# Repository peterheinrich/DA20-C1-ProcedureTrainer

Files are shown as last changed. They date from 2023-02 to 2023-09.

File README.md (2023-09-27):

# DA20-C1-ProcedureTrainer
DA20 Hardware Cockpit Simulator for Procedure Training (non approved simulator)

# Final Training Setup
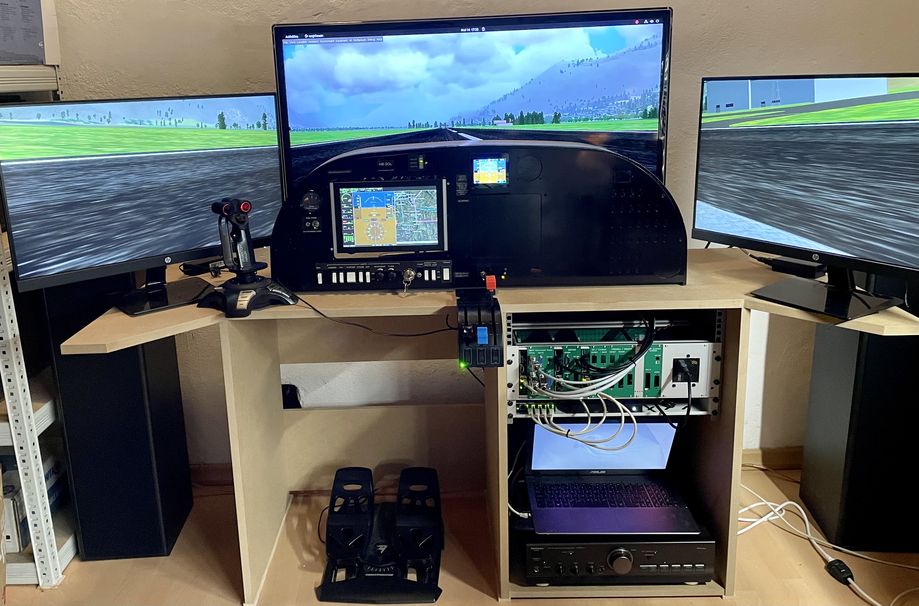
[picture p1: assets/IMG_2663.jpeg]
Final Training Setup


# Generic Instrument I/O Card based on Raspberry-PI CM4
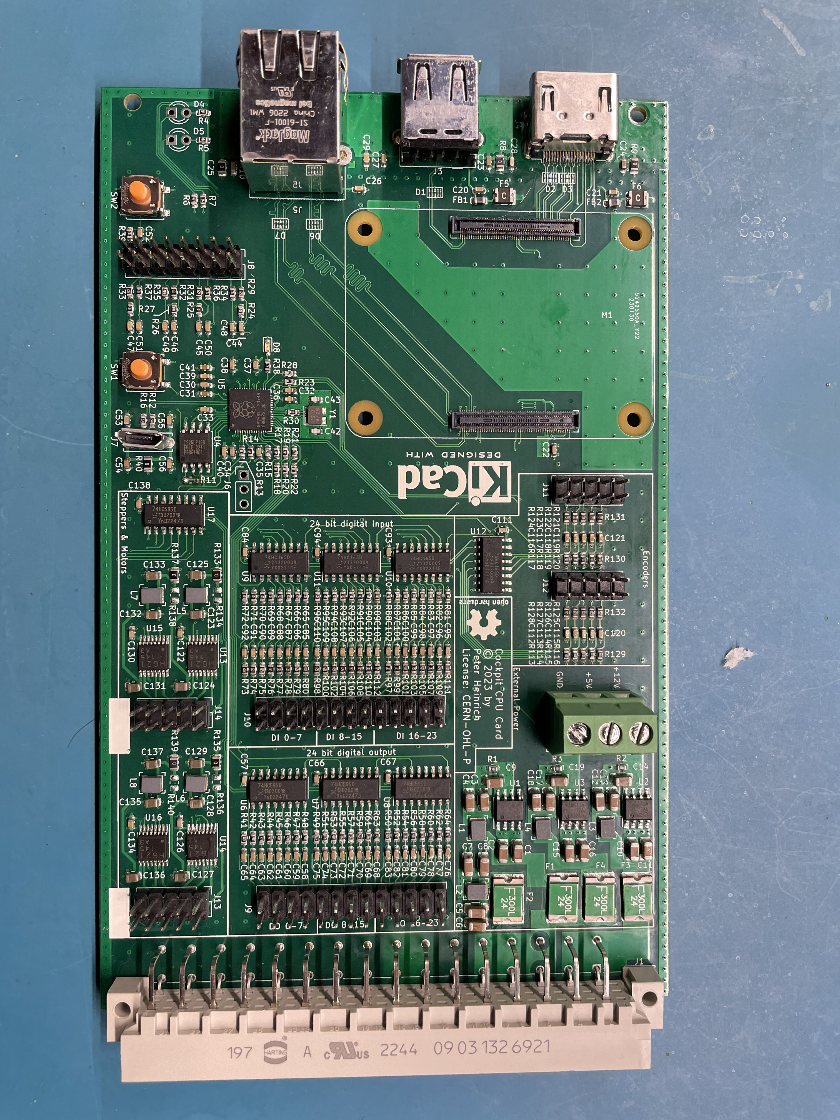
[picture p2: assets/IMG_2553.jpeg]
Cockpit CPU Card

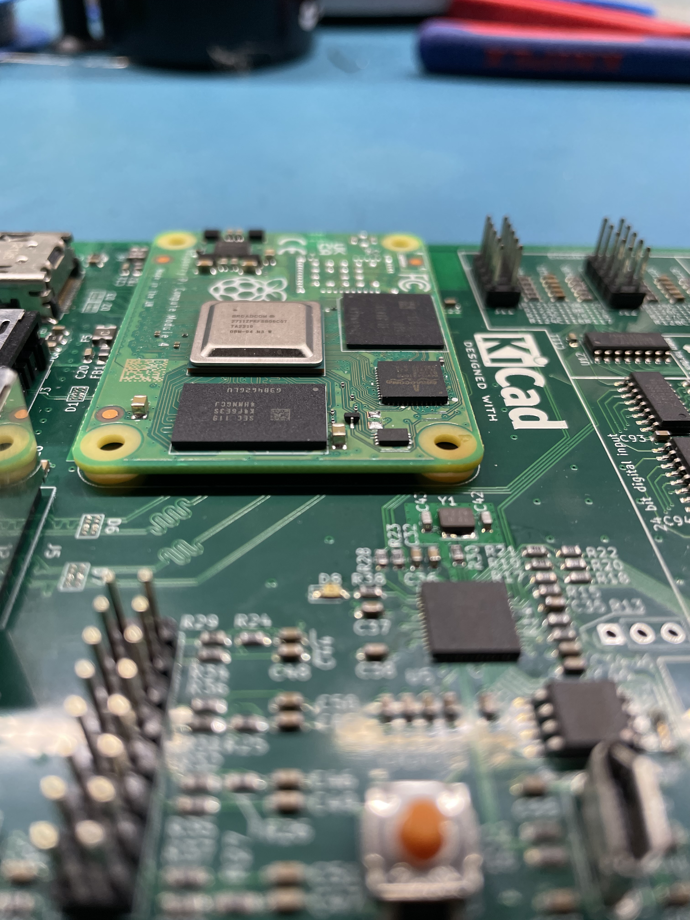
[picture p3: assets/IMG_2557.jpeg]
With Raspberry-PI CM4 installed


# Running with FgFs (FlightGear Flight Simulator)

/usr/local/fgfs.app/Contents/MacOS/fgfs --fg-scenery=/Users/peter/Development/flightgear/terraGIT --airport=LSMF --enable-auto-coordination --aircraft=DA20-C1 --httpd=8080 --generic=socket,out,10,255.255.255.255,30000,udp,glasspanel-stream --timeofday=noon --altitude=10000

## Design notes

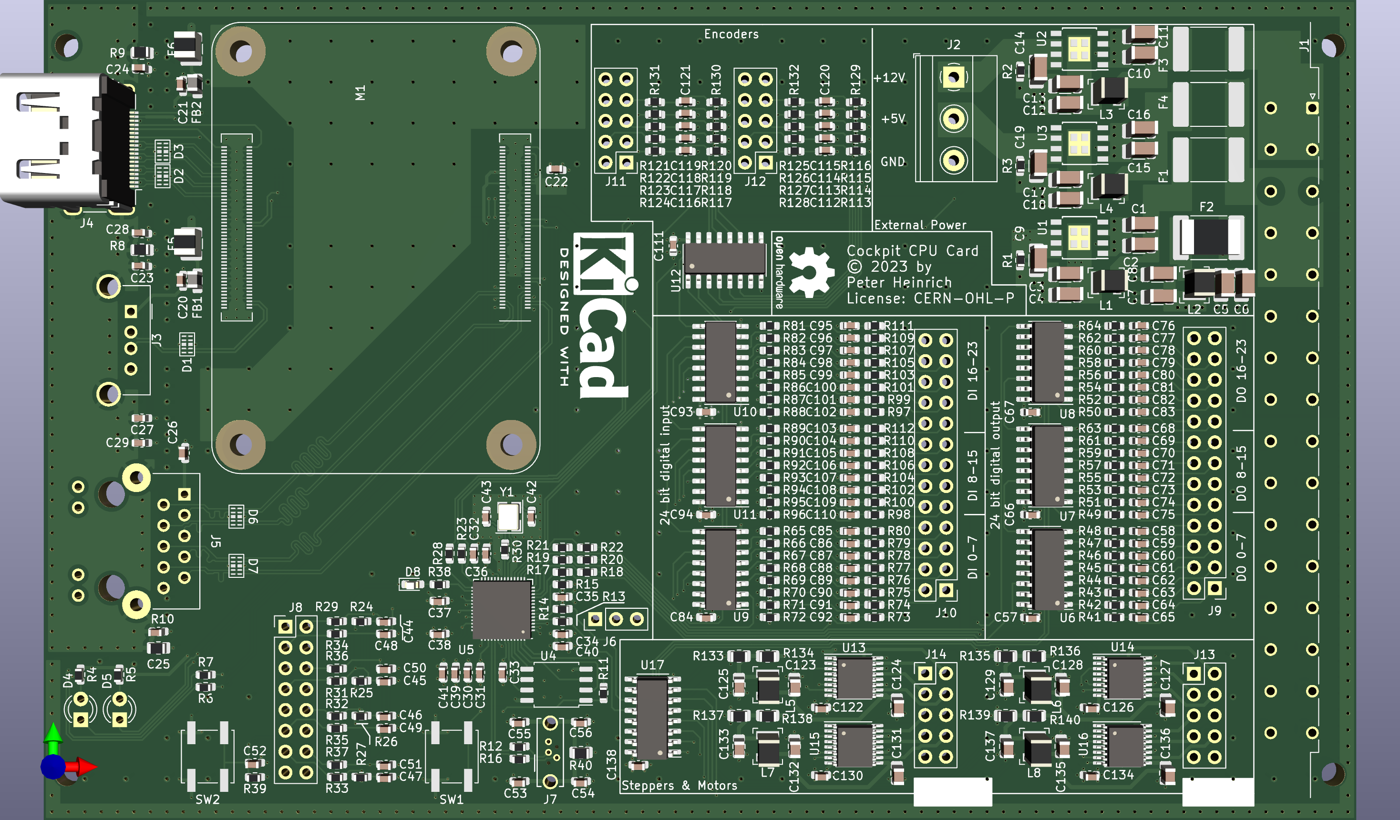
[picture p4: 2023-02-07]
assets/Cockpit-CPU-Card.png

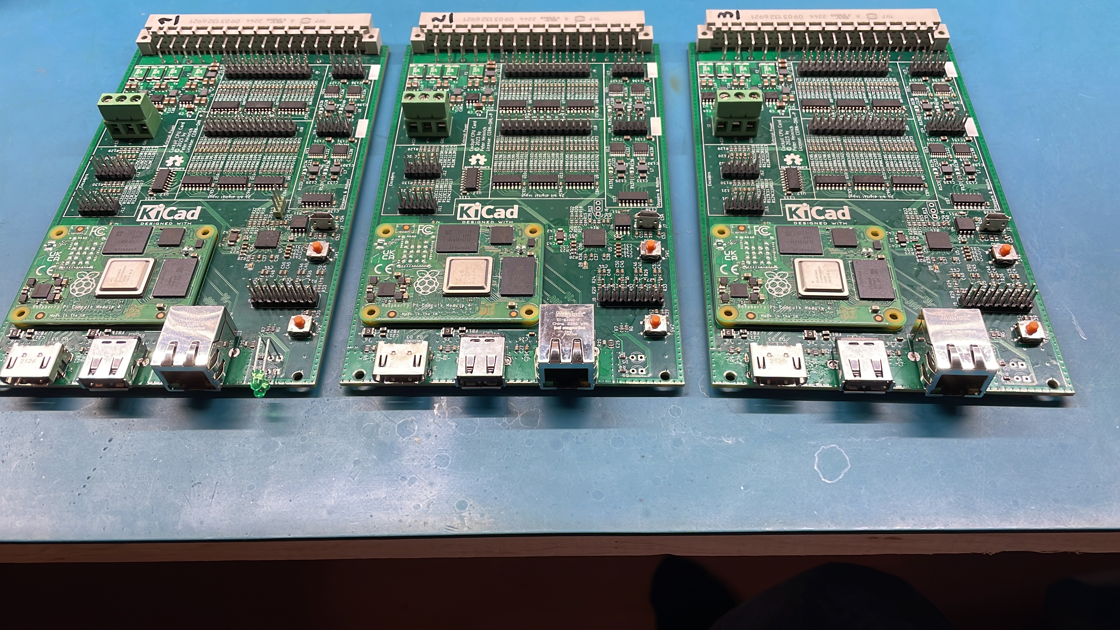
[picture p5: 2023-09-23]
assets/D262D218-E119-4301-A444-4E6CBF223C45.jpg

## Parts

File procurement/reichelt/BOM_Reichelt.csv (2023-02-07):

Quantity | Order Number | Description/MPN
1 | BQT BN323 | Netzteil be quiet! TFX Power 3 300W Gold
1 | BGT TFP 342 | Alu-Teilfrontplatten 128,4 x 213,2 x 2,5mm
6 | HS 25-14 | Hohlstecker Knickschutz, Ø außen: 5,5 mm, Ø innen: 2,5 mm
2 | HEBL 21 | Einbaubuchse Zentraleinbau, Ø außen: 5,6 mm, Ø innen: 2,1 mm
1 | BGT 384-240 | 19 Zoll-Baugruppenträger, 3HE 84TE, 238 mm tief
5 | LIYCY 10-5 | Steuerleitung 10x0,14mm², geschirmt, 5m-Ring
18 | KAPPE 25M | D-SUB-Kappe f. 25-polig D-Sub, metallisiert
8 | KAPPE 15M | D-SUB-Kappe f. 15-polig D-Sub, metallisiert
26 | KAPPE 09M | D-SUB-Kappe f. 9-polig D-Sub, metallisiert
12 | D-SUB ST 25 | D-SUB-Stecker, 25-polig, Lötkelch
15 | D-SUB BU 25 | D-SUB-Buchse, 25-polig, Lötkelch
18 | D-SUB ST 09 | D-SUB-Stecker, 9-polig, Lötkelch
2 | MOLEX 39301240 | Molex, Stiftleiste - Mini-Fit Jr - 2x12-polig - Stecker
5 | HAN 03 132 6921 | Messerleiste C, gewinkelt, 32-pol
15 | PFL 10 | Pfostenbuchse, 10-polig, mit Zugentlastung
1 | AWG 28-26G 3M | Flachbandkabel AWG28, 26-pol., grau, 3m-Ring
6 | D-SUB ST 25FB | D-SUB-Stecker, 25-pol, Flachbandkabel, ohne Isolator
5 | D-SUB ST 09FB | D-SUB-Stecker, 9-pol, Flachbandkabel, ohne Isolator
10 | BGT FSC 160 | Kartenführung zum Einrasten, 160 mm (Fischer)
5 | BGT SFP 304 | Alu-Steckfrontplatten 128,4 x 20,0 x 2,5mm
5 | D-SUB BU 09FB | D-SUB-Buchse, 9-pol, Flachbandkabel, ohne Isolator
4 | D-SUB BU 15FB | D-SUB-Buchse, 15-pol, Flachbandkabel, ohne Isolator
3 | D-SUB BU 25FB | D-SUB-Buchse, 25-pol, Flachbandkabel, ohne Isolator
5 | PFL 16 | Pfostenbuchse, 16-polig, mit Zugentlastung
10 | PFL 26 | Pfostenbuchse, 26-polig, mit Zugentlastung
52 | SV U | D-SUB-Befestigungssatz, 2 Bolzen mit Muttern
1 | NKSK CH 180 | Netzkabel, CH Stecker, Typ J, 1,8 m, schw, C13
5 | HAN 03 232 6824 | Federleiste C, gerade, 32-pol
21 | D-SUB BU 09 | D-SUB-Buchse, 9-polig, Lötkelch
8 | D-SUB ST 15 | D-SUB-Stecker, 15-polig, Lötkelch
2 | LIYCY 25-5 | Steuerleitung 25x0,14mm², geschirmt, 5m-Ring
1 | BGT 384-2 | Gewindestreifen
4 | LIYCY 04-5 | Steuerleitung 4x0,14mm², geschirmt, 5m-Ring
6 | HEBL 25 | Einbaubuchse Zentraleinbau, Ø außen: 5,6 mm, Ø innen: 2,5 mm
2 | HS 21-9 | Hohlstecker Knickschutz, Ø außen: 5,5 mm, Ø innen: 2,1 mm

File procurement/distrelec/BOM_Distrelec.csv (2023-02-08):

Quantity | Order Number | Description/MPN
204 | 300-56-474 | 1550603SAF1200T5E

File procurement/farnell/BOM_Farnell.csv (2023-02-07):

Quantity | Order Number | Description/MPN
114 | 3013515 | CL31A226KAHNNNE
618 | 3013413 | CL10B104KO8NNNC
12 | 3013384 | CL10A105KO8NNNC
12 | 2773145 | C0603C270K5GACTU
72 | 3013460 | CL21A226MPCLRNC
30 | 4035994 | HSP054-4N10
12 | 1581123 | MCL034GT
6 | 2322073 | 150060VS75000
24 | 3020672 | MC011393
12 | 1596997 | 1210L020WR
12 | 1515661 | BLM21PG221SN1D
6 | 1096917 | 09 04 132 6921
6 | 2008005 | MC000035
6 | 1450206 | 67643-0910.
6 | 3465045 | 208658-1001
6 | 1572191 | SI-61001-F
6 | 1248141 | 826926-3
6 | 2470821 | 614105150721
6 | 1593445 | 2213S-16G
6 | 3225996 | M20-9761346
6 | 3225996 | M20-9761346
6 | 2751378 | 67997-410HLF
6 | 2751378 | 67997-410HLF
12 | 2751378 | 67997-410HLF
48 | 3974271 | SRP3212-3R3M
12 | 2427679 | DF40C-100DS-0.4V(51)
504 | 2073356 | MCMR06X103 JTL
174 | 2073508 | MCMR06X4700FTL
6 | 2447359 | MCWR06X3301FTL
12 | 2447316 | MCWR06X27R0FTL
66 | 2447339 | MCWR06X3300FTL
6 | 2073348 | MCMR06X1001FTL
24 | 9333681 | MC01W08050R
12 | 2320051 | KSC441J70SHLFS
18 | 2480570 | BTS50301EJAXUMA1
6 | 2901144 | IS25LP128F-JBLE
6 | 3766082 | RP2040CT
24 | 1201269 | 74HC595D,118
24 | 1201249 | 74HC165D,653
24 | 3869999 | TC78H621FNG
6 | 2308709 | ABM8G-12.000MHZ-18-D2Y-T

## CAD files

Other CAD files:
mcad/G5_Case.scad

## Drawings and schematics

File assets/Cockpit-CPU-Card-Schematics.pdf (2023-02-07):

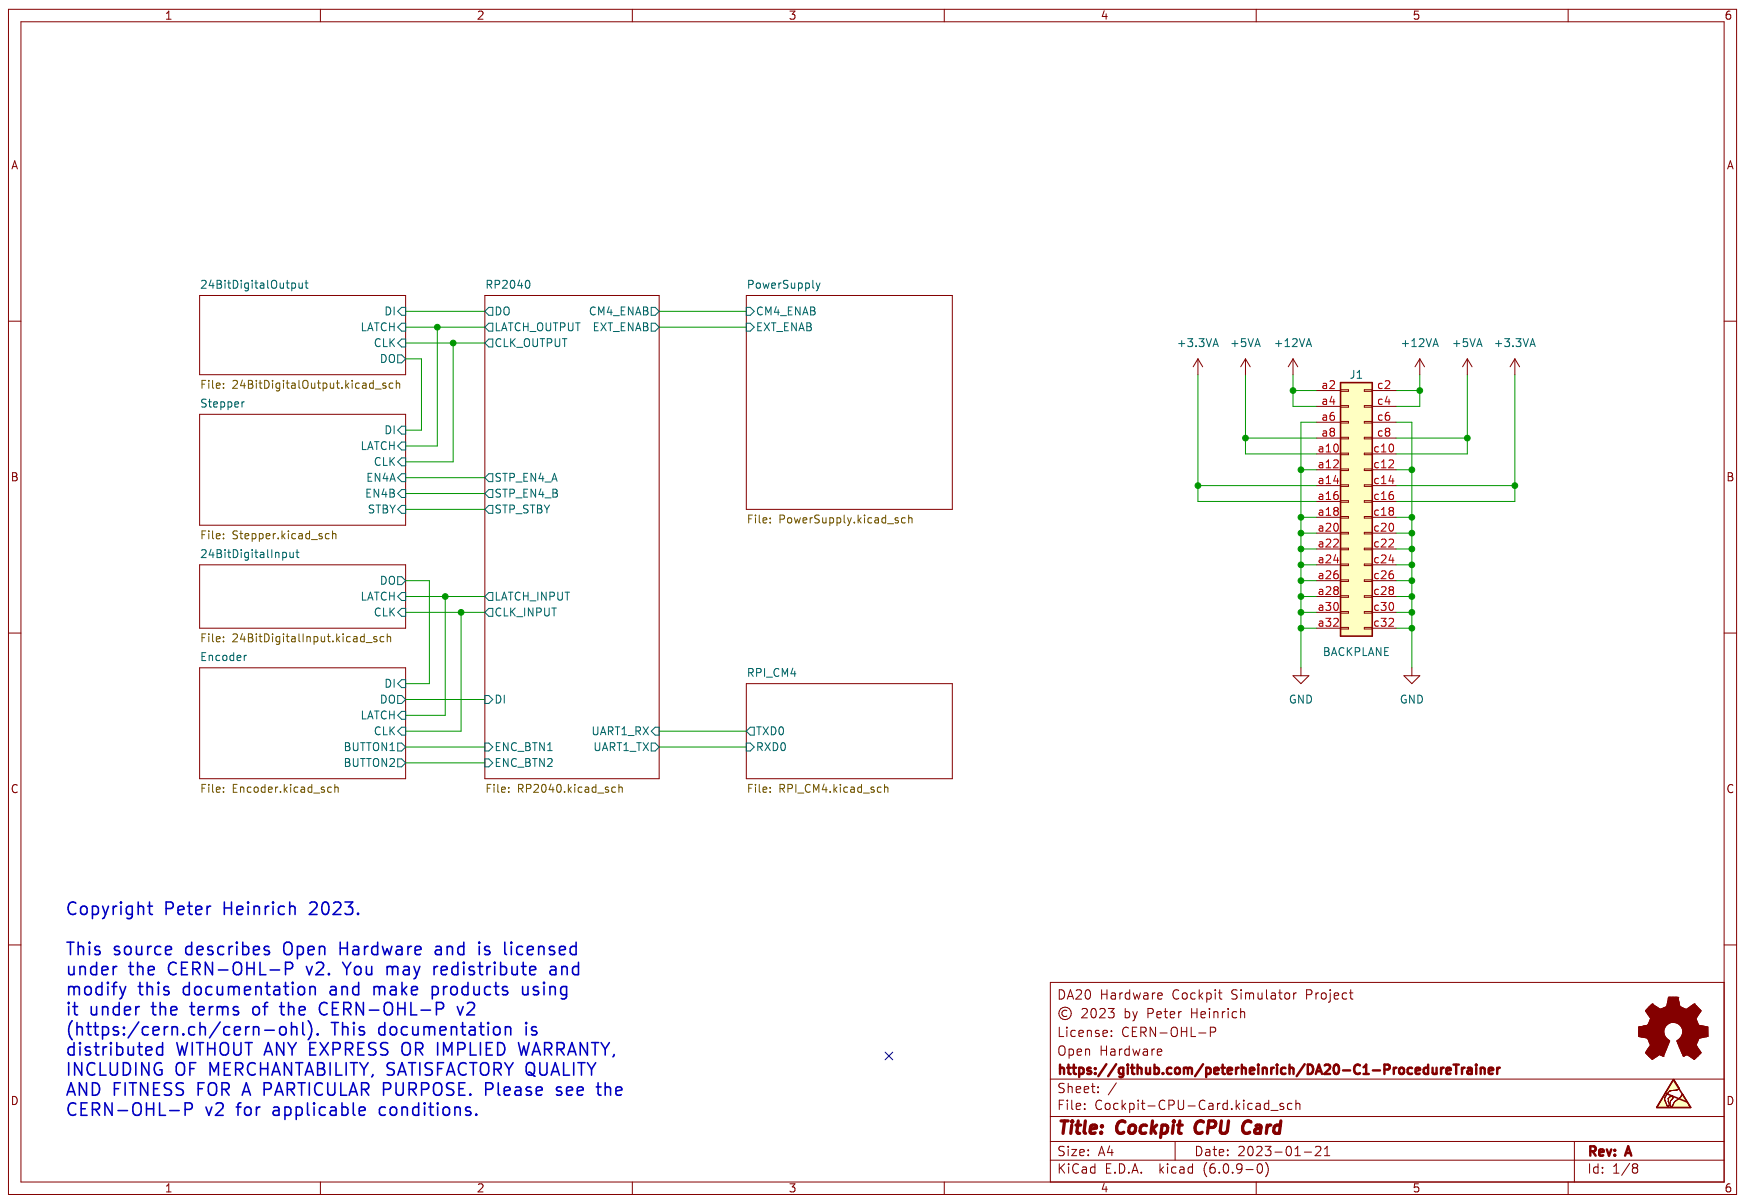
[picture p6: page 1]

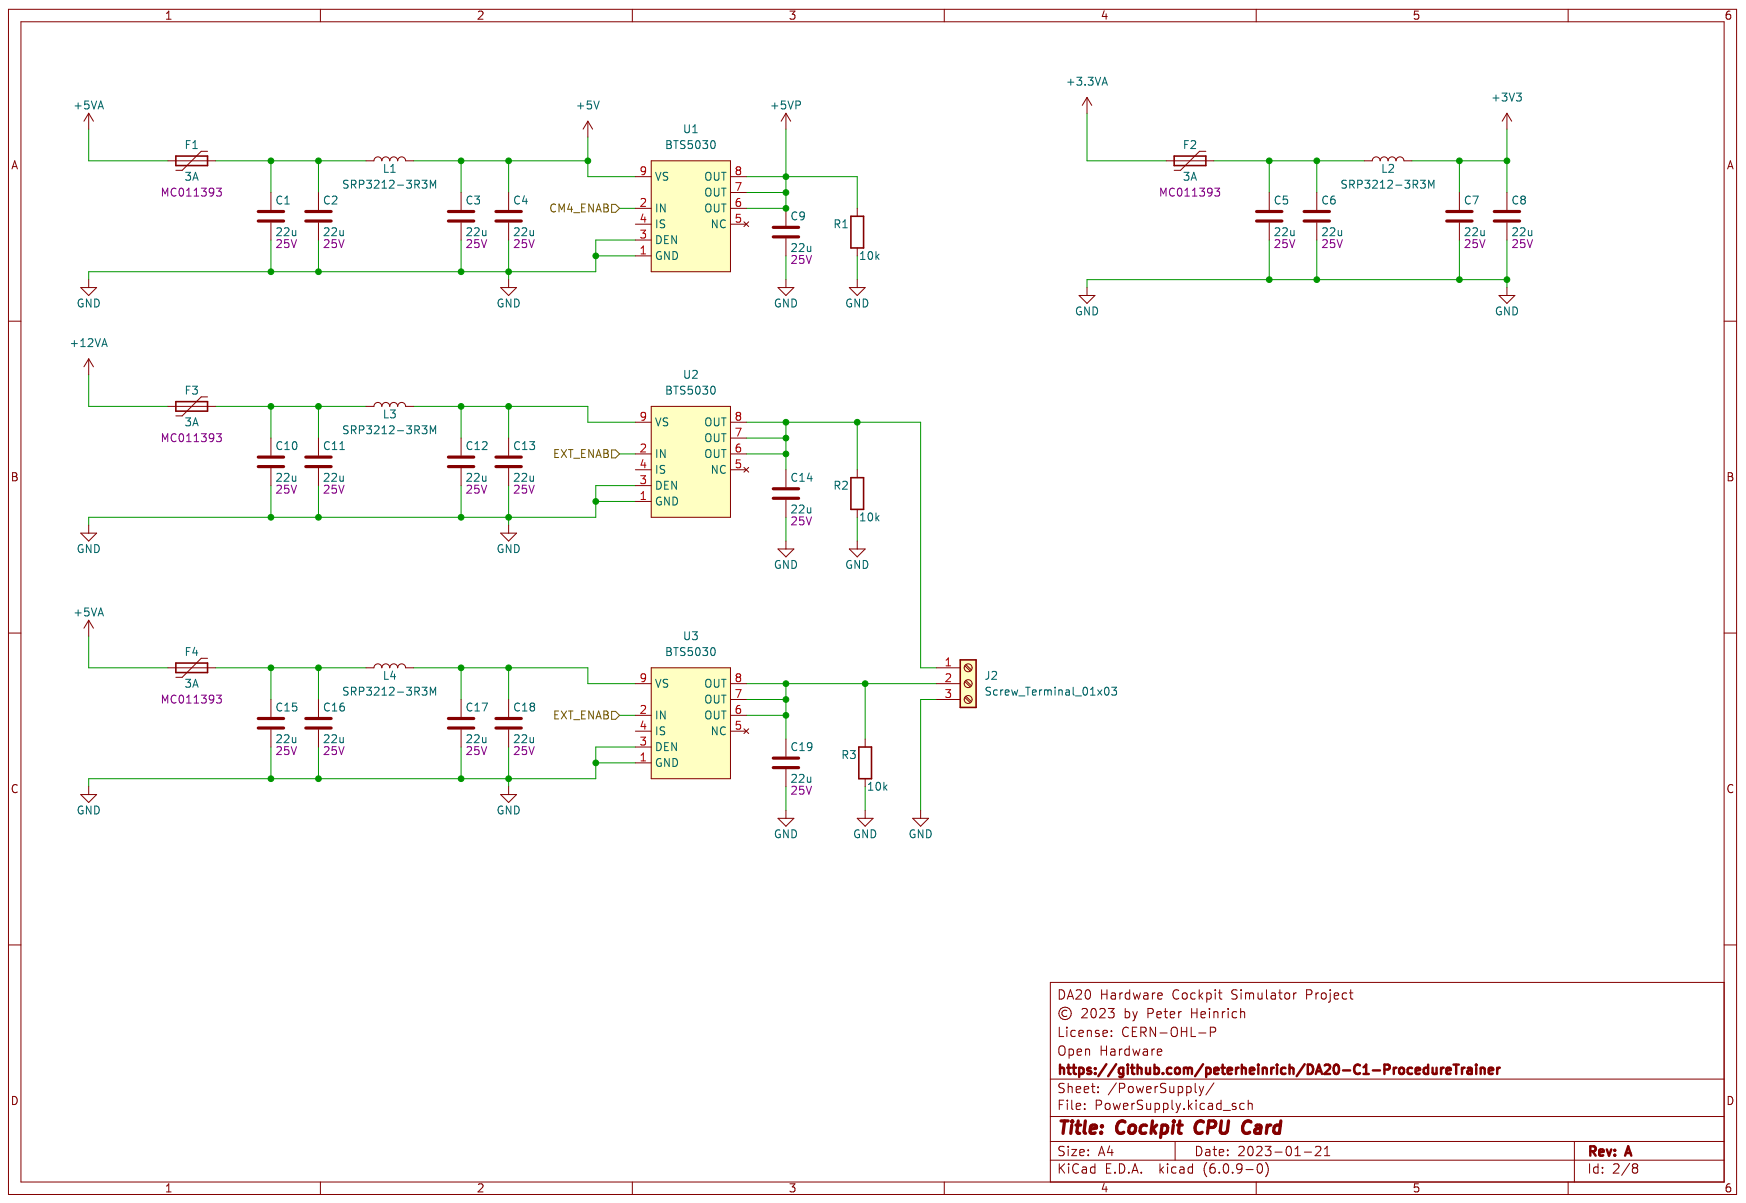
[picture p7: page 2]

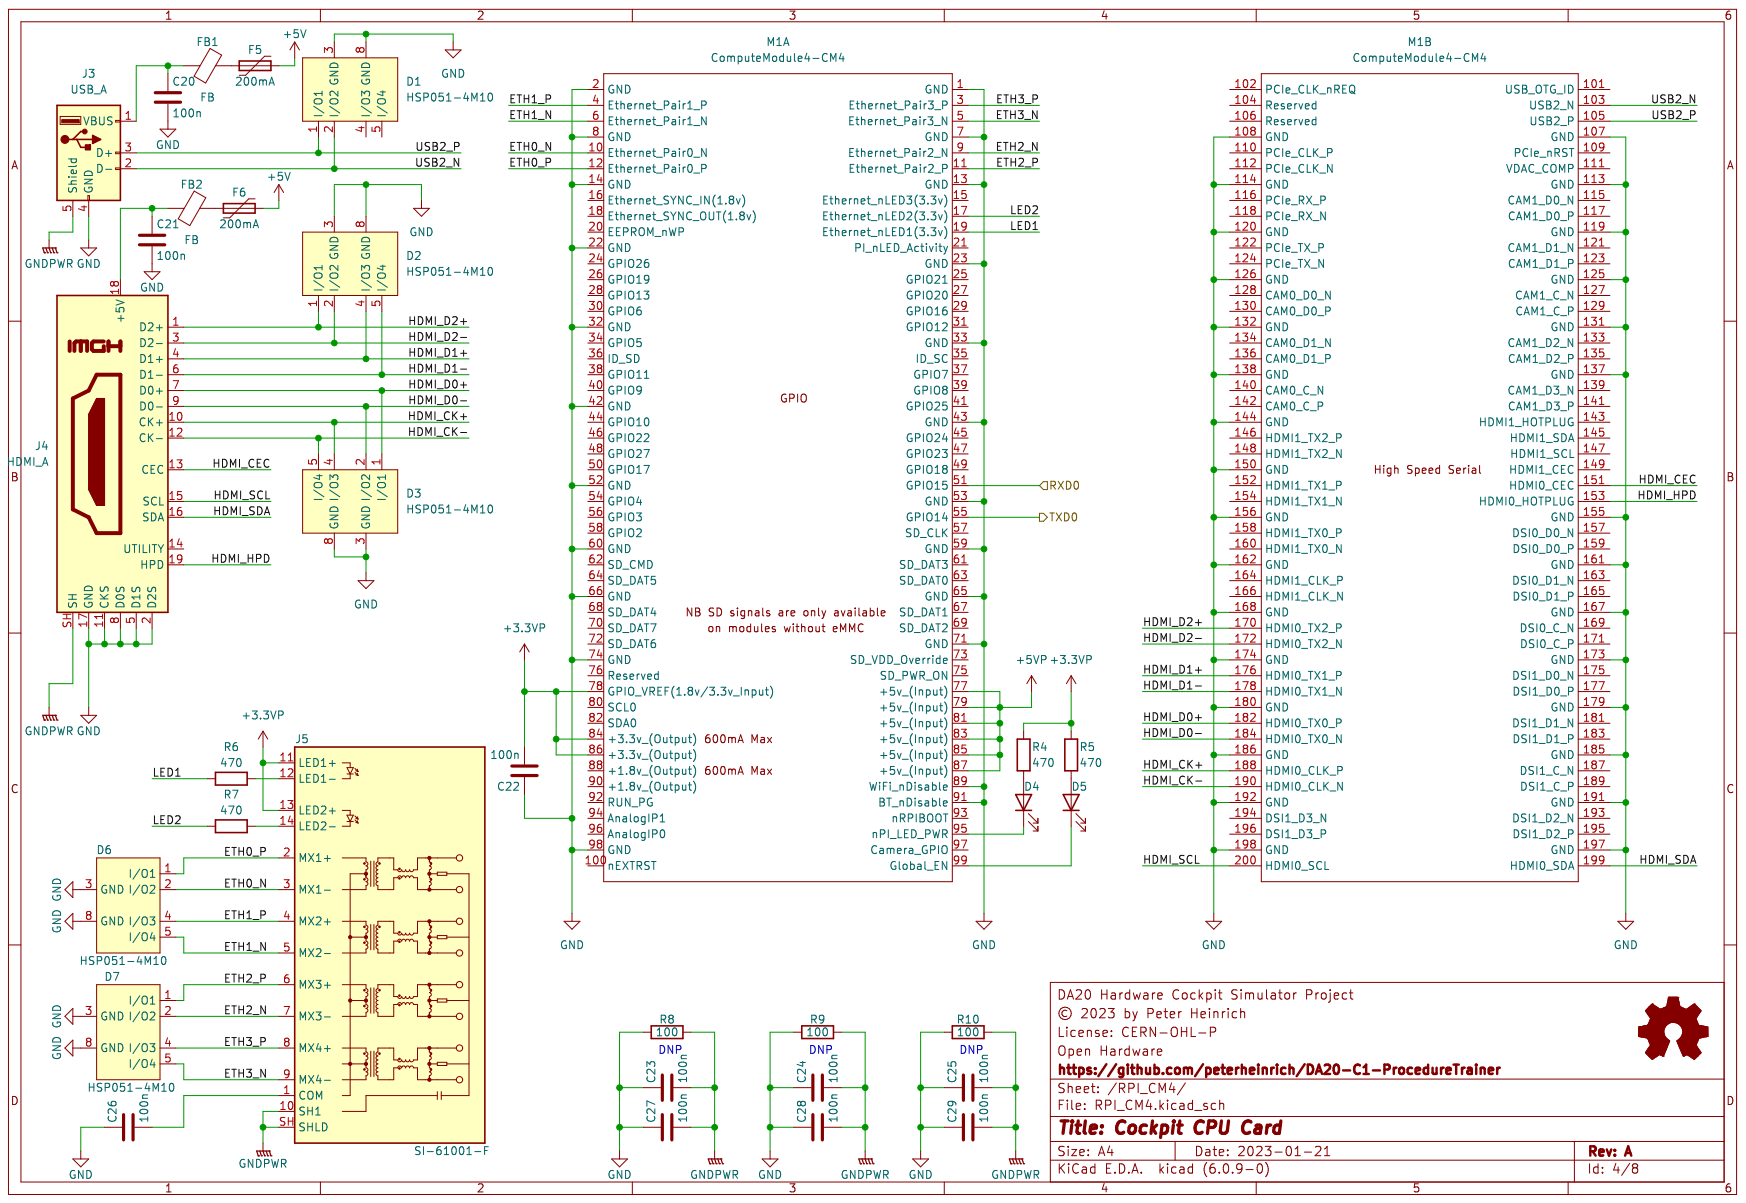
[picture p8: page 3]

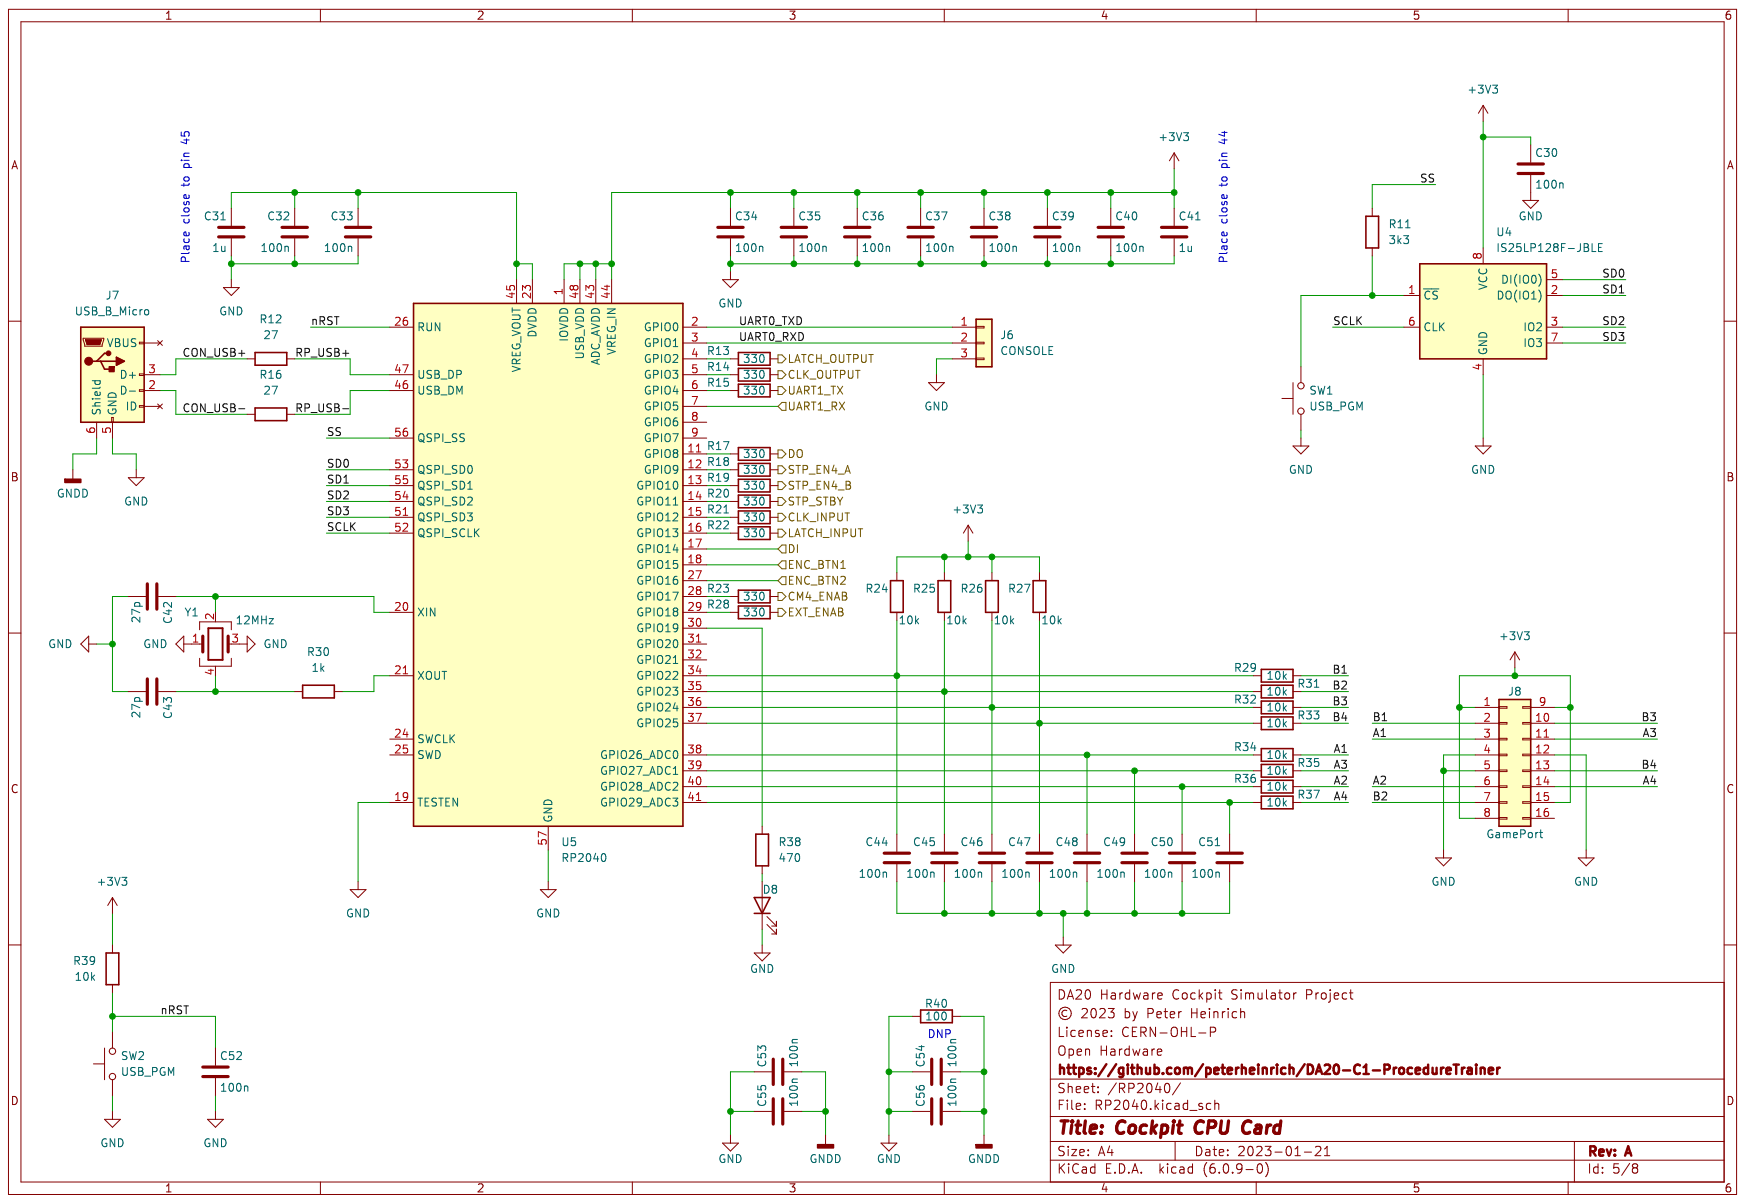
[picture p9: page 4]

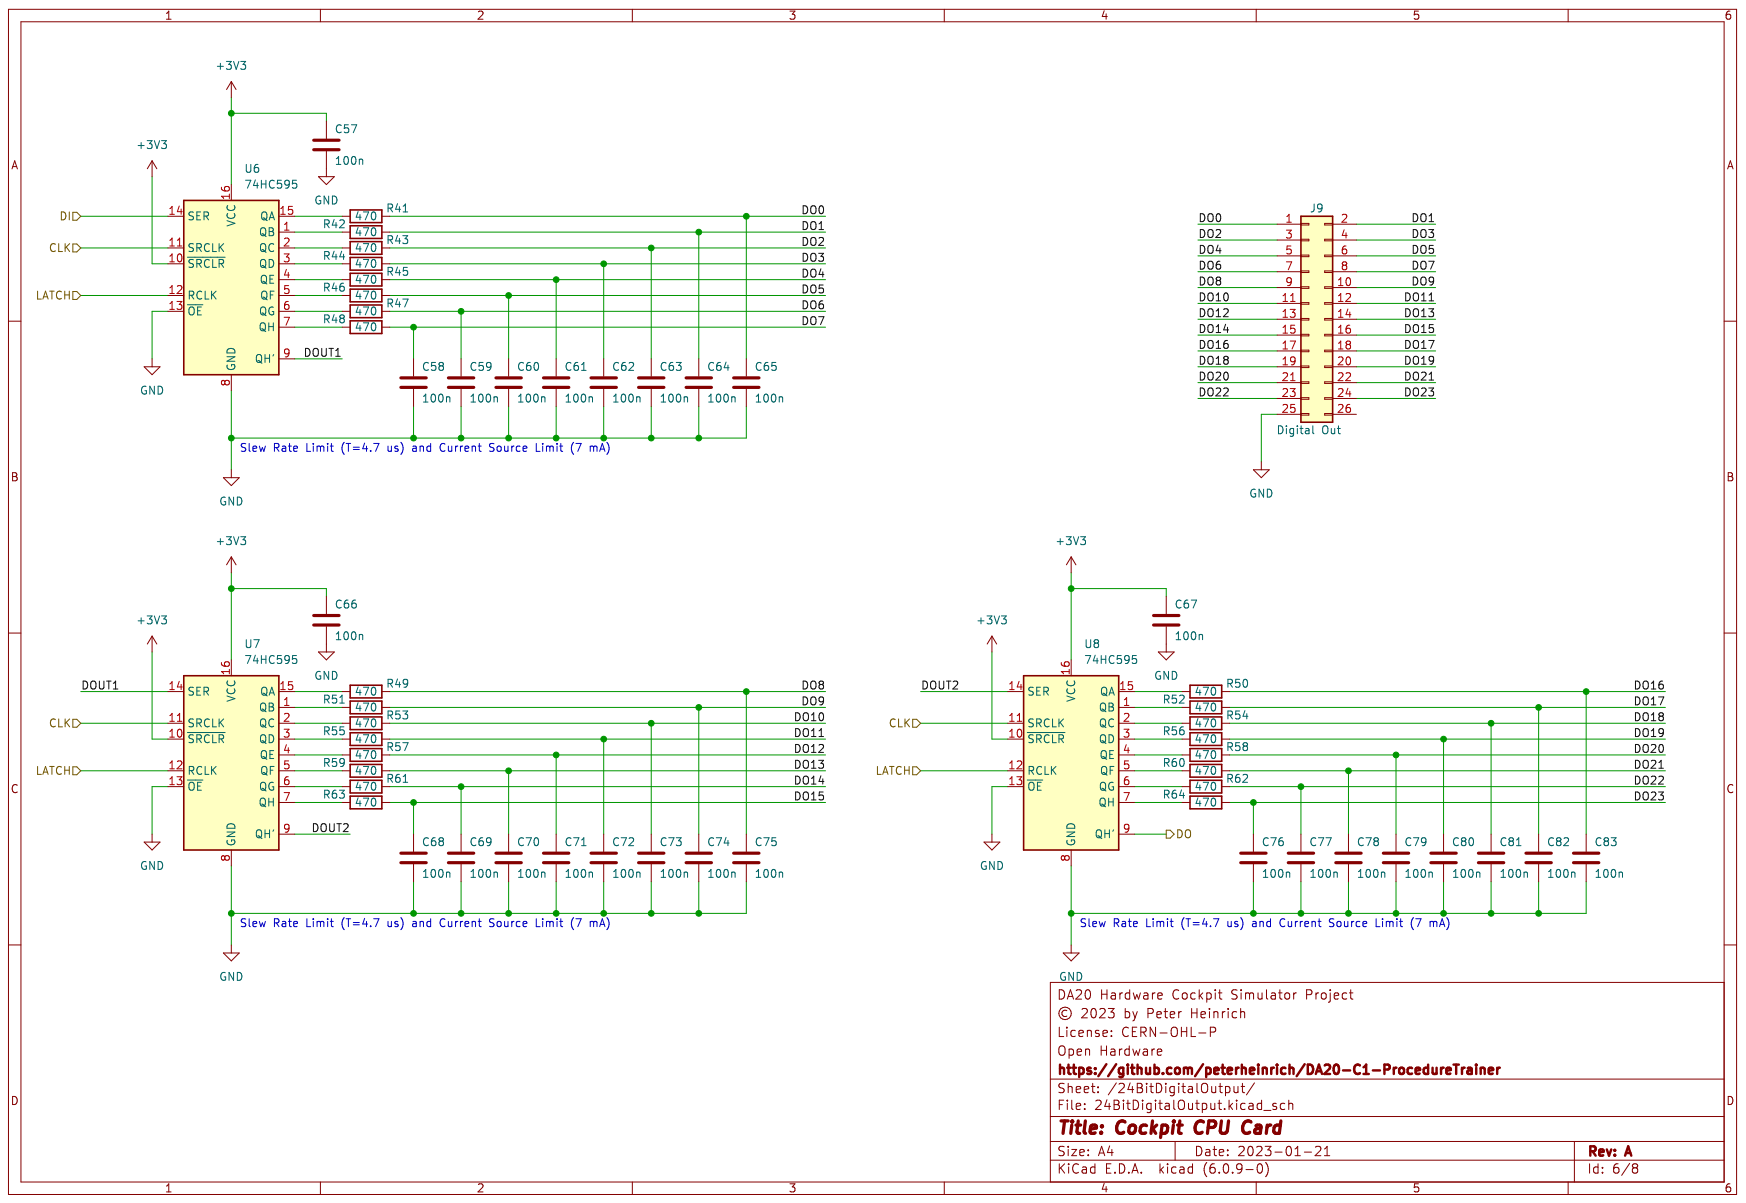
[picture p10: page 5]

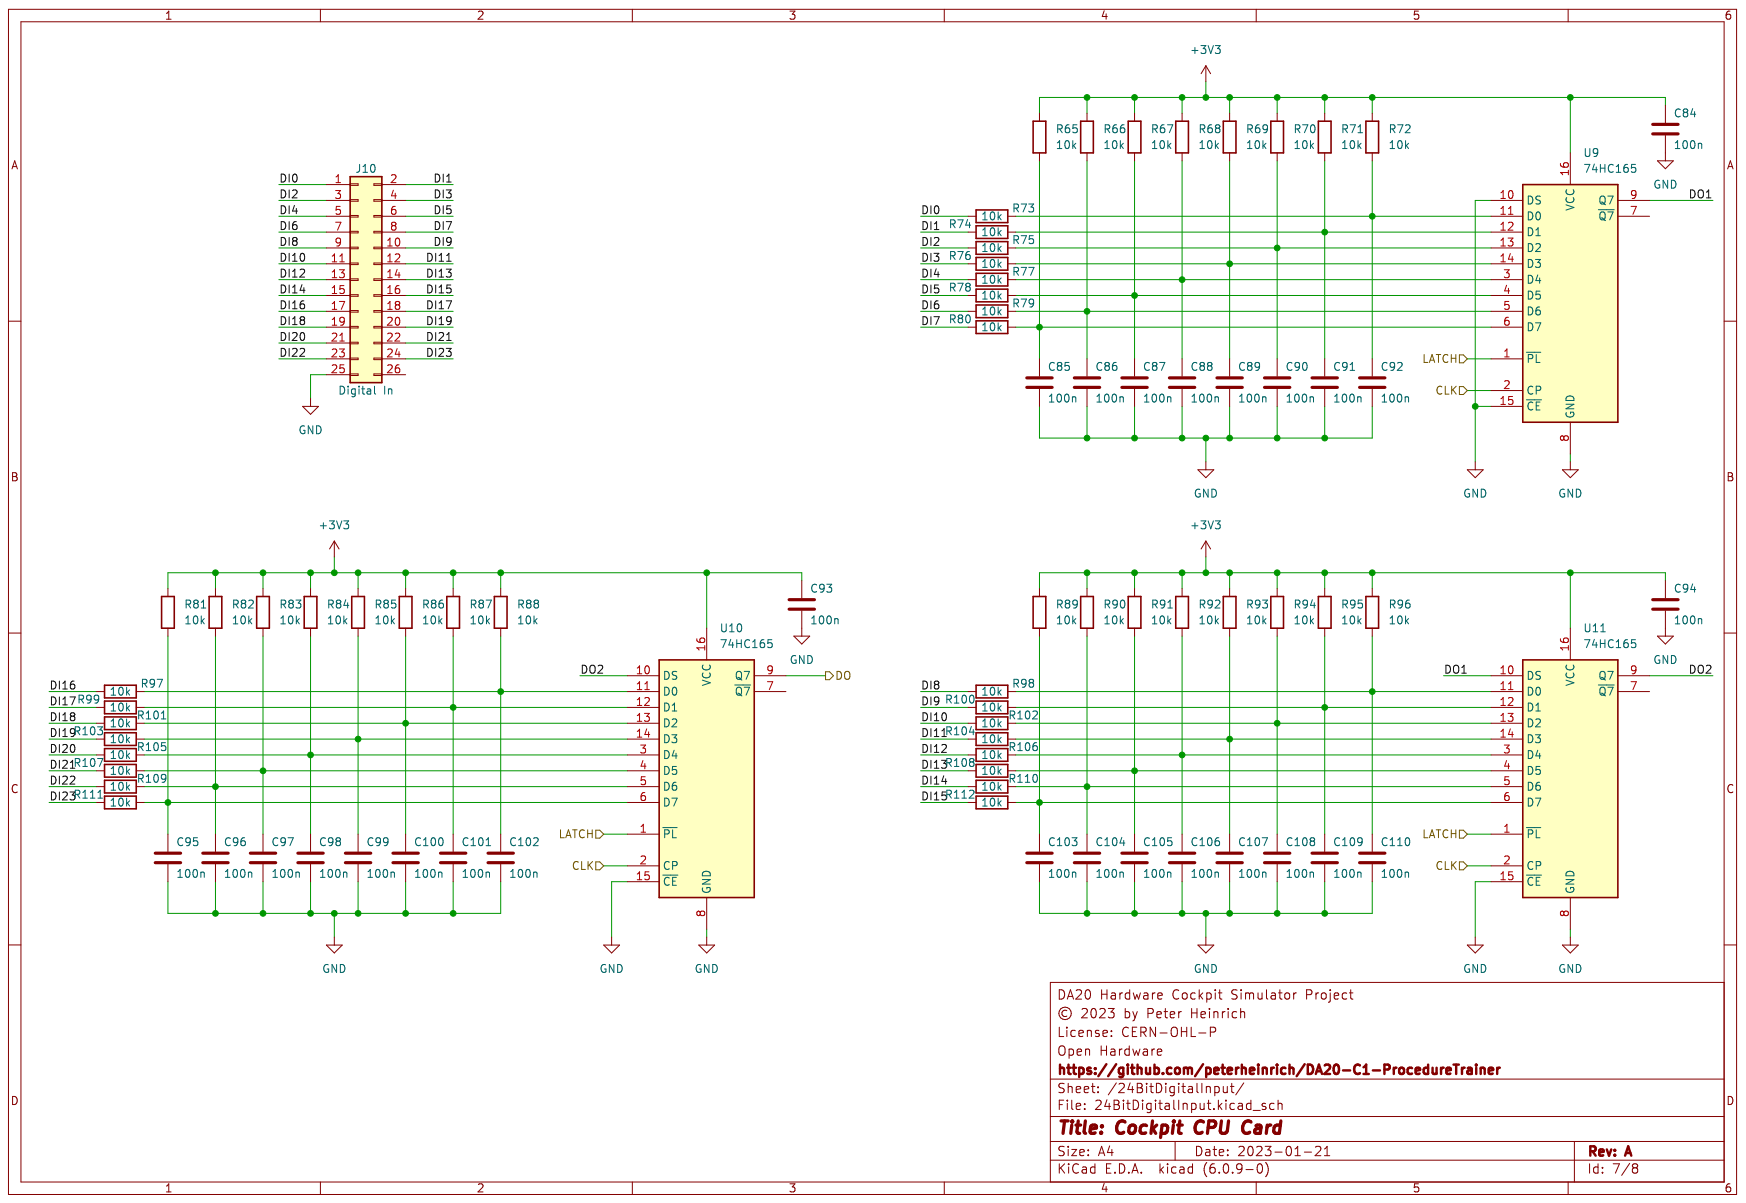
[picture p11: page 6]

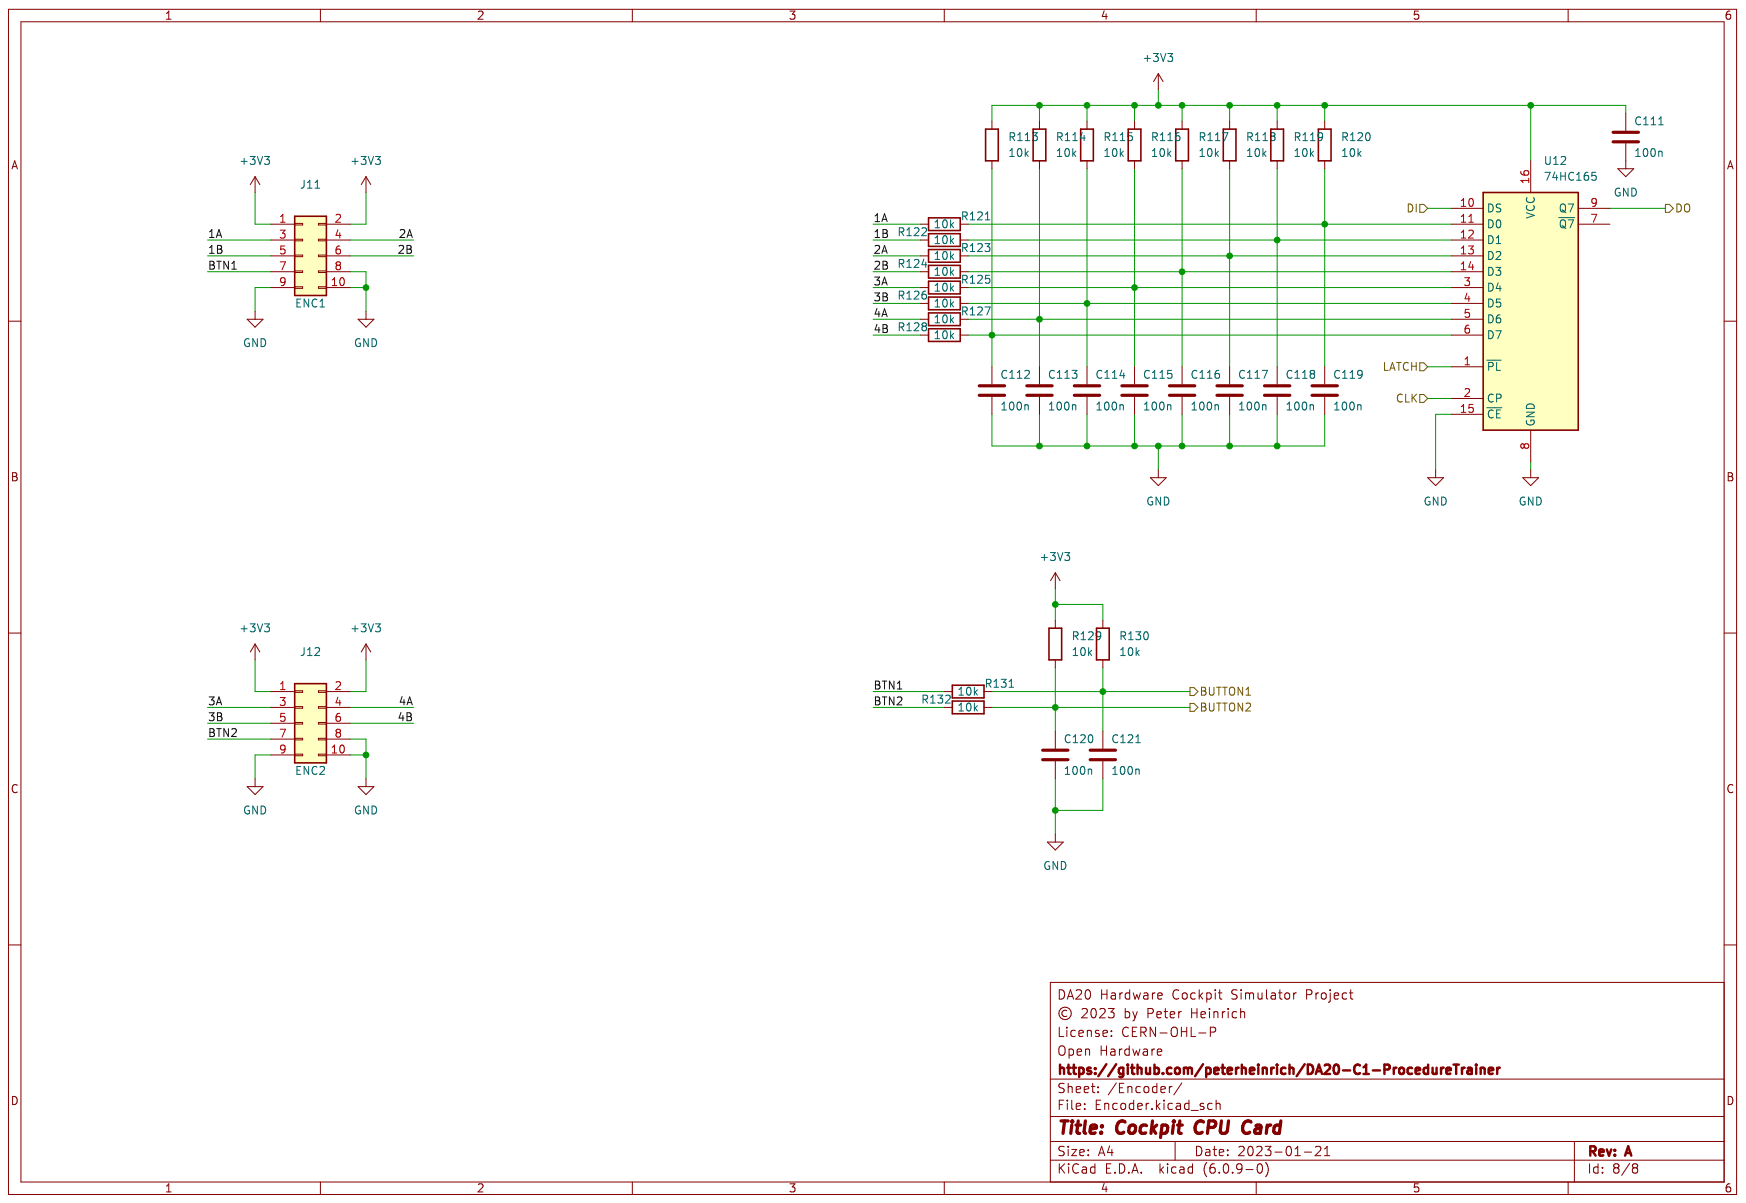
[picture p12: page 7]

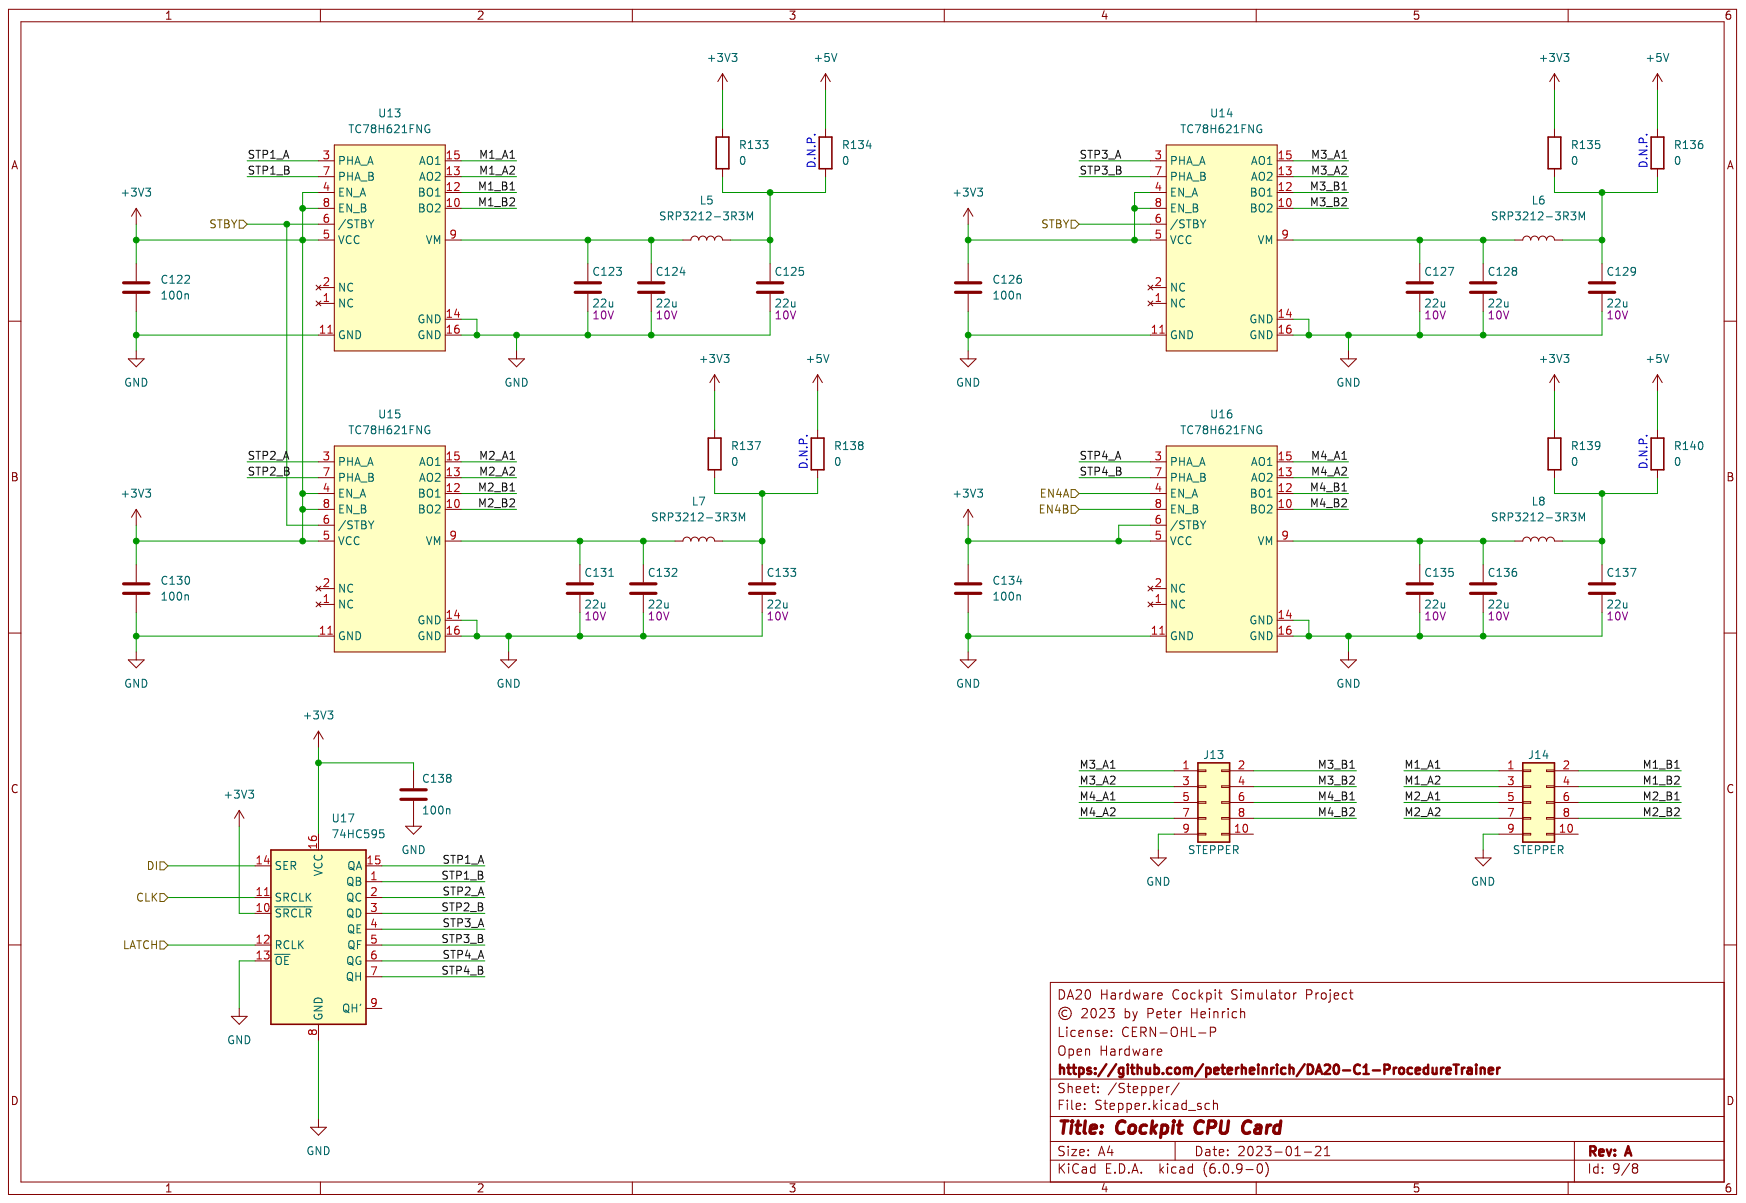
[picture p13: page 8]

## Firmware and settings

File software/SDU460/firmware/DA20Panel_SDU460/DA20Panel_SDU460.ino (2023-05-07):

#include "RPi_Pico_TimerInterrupt.h"
#include "RPi_Pico_TimerInterrupt.h"


#define LED         19

#define OUT_LATCH   2
#define OUT_CLK     3
#define OUT_D       8

#define IN_LATCH    13
#define IN_CLK      12
#define IN_D        14

#define IN_D        14
#define CM4_ENAB    17
#define EXT_ENAB    18


volatile unsigned int outputRegister = 0;
volatile unsigned int inputRegister = 0;


#define STP_M1_PHASE_A_BIT (1 << 24)
#define STP_M1_PHASE_B_BIT (1 << 25)
#define STP_M2_PHASE_A_BIT (1 << 26)
#define STP_M2_PHASE_B_BIT (1 << 27)
#define STP_M3_PHASE_A_BIT (1 << 28)
#define STP_M3_PHASE_B_BIT (1 << 29)
#define STP_M4_PHASE_A_BIT (1 << 30)
#define STP_M4_PHASE_B_BIT (1 << 31)

#define STEP_SBY          11
#define STEP_M4_EN_A      9
#define STEP_M4_EN_B      10

RPI_PICO_Timer ITimer1(1);


volatile unsigned long timer = 0;
volatile int state = 0;  
volatile bool flagSendUpdate = false;

bool TimerHandler(struct repeating_timer *t)
{ 
  timer ++;
  
  // moveSteppers(0);
  unsigned int inputRegisterNew = readInputRegister();
  if(inputRegister != inputRegisterNew) {
    inputRegister = inputRegisterNew;
    flagSendUpdate = true;
  }
  //readInputAnalog();
  return true;
}

#define TIMER_FREQ_HZ        500

void setup() {
  pinMode(LED, OUTPUT);
  pinMode(OUT_LATCH, OUTPUT);
  pinMode(OUT_CLK, OUTPUT);
  pinMode(OUT_D, OUTPUT);
  pinMode(STEP_SBY, OUTPUT);

  pinMode(IN_LATCH, OUTPUT);
  pinMode(IN_CLK, OUTPUT);
  pinMode(IN_D, INPUT);


  pinMode(CM4_ENAB, OUTPUT);
  pinMode(EXT_ENAB, OUTPUT);

  digitalWrite(CM4_ENAB,1);
  digitalWrite(EXT_ENAB,1);


  digitalWrite(OUT_LATCH,0);
  digitalWrite(OUT_CLK,0);
  digitalWrite(OUT_D,0);
  digitalWrite(IN_LATCH,0);
  digitalWrite(IN_CLK,0);
  digitalWrite(STEP_SBY,1);

  Serial2.setRX(5);
  Serial2.setTX(4);
  Serial2.begin(9600);

  //Serial2.setRX(5);
  //Serial2.setTX(4);
  //Serial2.begin(9600);

  ITimer1.attachInterrupt(TIMER_FREQ_HZ, TimerHandler);
  Serial2.setTimeout(100);
}

char buffer[64];
// the loop routine runs over and over again forever:
void loop() {
  
  if(flagSendUpdate) {
    sendByteValueHex((inputRegister >> 24) & 0xFF);
    Serial2.print(",");
    sendByteValueHex((inputRegister >> 16) & 0xFF);
    Serial2.print(",");
    sendByteValueHex((inputRegister >> 8) & 0xFF);
    Serial2.print(",");
    sendByteValueHex((inputRegister) & 0xFF);
    Serial2.println();
    flagSendUpdate = false;
  }
  Serial2.readBytesUntil('\n', buffer, 64);
  String line = String(buffer);
  char byteBuffer[8];
  char *end;
  line.substring(0,2).toCharArray(byteBuffer, 8);
  unsigned char c0 = strtol(byteBuffer,&end,16);
  line.substring(3,5).toCharArray(byteBuffer, 8);
  unsigned char c1 = strtol(byteBuffer,&end,16);
  line.substring(6,8).toCharArray(byteBuffer, 8);
  unsigned char c2= strtol(byteBuffer,&end,16);  
  outputRegister = c0 | c1 << 8 | c2 << 16;

  writeOutputRegister();

  
}

void sendByteValueHex(unsigned short val) {
  if(val < 16) Serial2.print("0");
  Serial2.print(val, HEX);
}



void writeOutputRegister() {
  unsigned int v;
  for(int i = 0; i < 32; i++) {
    v = outputRegister >> 31-i;
    digitalWrite(OUT_D,v & 0x01);
    // Clock
    delayMicroseconds(1);   
    digitalWrite(OUT_CLK,1);
    delayMicroseconds(1);   
    digitalWrite(OUT_CLK,0);
    delayMicroseconds(1);   

  }
  // Latch
  delayMicroseconds(1);   
  digitalWrite(OUT_LATCH,1);
  delayMicroseconds(1);   
  digitalWrite(OUT_LATCH,0);
}

unsigned int readInputRegister() {
  unsigned int res = 0;
  // Latch
  digitalWrite(IN_LATCH,1);
  delayMicroseconds(5);   
   
  for(int i = 0; i < 32; i++) {
    // Clock
        res |= digitalRead(IN_D) << 31-i;

    delayMicroseconds(1);   
    digitalWrite(IN_CLK,1);
    delayMicroseconds(1);   
    digitalWrite(IN_CLK,0);
  }

  digitalWrite(IN_LATCH,0);
  return res;
}


volatile char stp1_state = 0;
volatile int stp1_pos = 0;

void moveSteppers(int targetPos) {
  if(targetPos > stp1_pos) {
    moveStepperSingleStep(1);
  }
  if(targetPos < stp1_pos) {
    moveStepperSingleStep(0);
  }
}

void moveStepperSingleStep(char dir) {
  switch(state) {
    case 0:
      outputRegister &= ~STP_M1_PHASE_A_BIT;
      outputRegister |= STP_M1_PHASE_B_BIT;
      dir?stp1_state = 1:stp1_state = 3;
      break;
    case 1:
      outputRegister |= STP_M1_PHASE_A_BIT;
      outputRegister |= STP_M1_PHASE_B_BIT;
      dir?stp1_state = 2:stp1_state = 0;
      break;
    case 2:
      outputRegister |= STP_M1_PHASE_A_BIT;
      outputRegister &= ~STP_M1_PHASE_B_BIT;
      dir?stp1_state = 3:stp1_state = 1;
      break;
    case 3:
      outputRegister &= ~STP_M1_PHASE_A_BIT;
      outputRegister &= ~STP_M1_PHASE_B_BIT;      
      dir?stp1_state = 0:stp1_state = 2;
      break;
    default:
      return;
  }
  dir?stp1_pos++:stp1_pos--;
  writeOutputRegister();

}

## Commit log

2023-02-07 Adding PDF Schematics
2023-02-07 Fixing wrong resistor values
    [24BitDigitalInput.kicad_sch, Cockpit-CPU-Card.kicad_sch, Encoder.kicad_sch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]
2023-02-08 120R from Distrelec
    [24BitDigitalInput.kicad_sch, Cockpit-CPU-Card.kicad_sch, Encoder.kicad_sch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]
2023-02-14 Updating resistor values
    [Cockpit-CPU-Card.kicad_sch, RP2040.kicad_sch]
2023-02-19 Changing crystal load capacitors to 10p
    [Cockpit-CPU-Card.kicad_sch, RP2040.kicad_sch]
2023-03-05 PanelInterface Description added
    [RP2040.kicad_sch]
2023-03-05 Adding G5 CAD files
    [G5_Case.scad]
